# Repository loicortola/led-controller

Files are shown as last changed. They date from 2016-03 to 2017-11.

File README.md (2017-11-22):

# Led Controller

All-in-one OpenSource & Open Hardware Smartphone-controlled Led Controller for ESP-8266.  

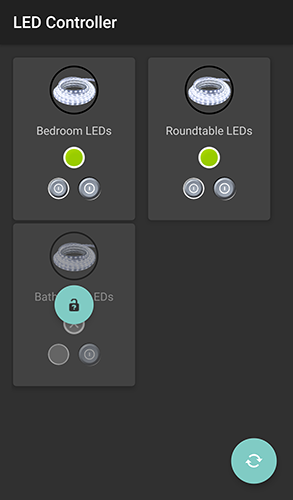
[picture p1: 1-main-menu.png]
main-menu

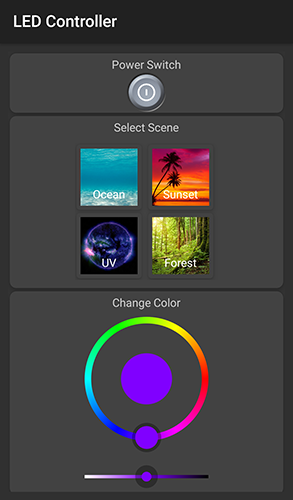
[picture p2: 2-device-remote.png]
device-remote


## Requirements

The current version has been rewritten entirely in C/C++ to use along with Arduino IDE.

 * Install Arduino IDE
 * [Install ESP8266 model](https://github.com/esp8266/Arduino)
 * [Install ESP8266 Arduino filesystem uploader plugin](https://github.com/esp8266/arduino-esp8266fs-plugin)
 * Install EAGLE or KiCAD (only if you want to edit the board hardware design)
**NB: You can find a previous version for NodeMCU (in LUA) in previous commits.**

## Schematics
This board is Open-Hardware.  
All parts and schematics are available in the hardware folder.  
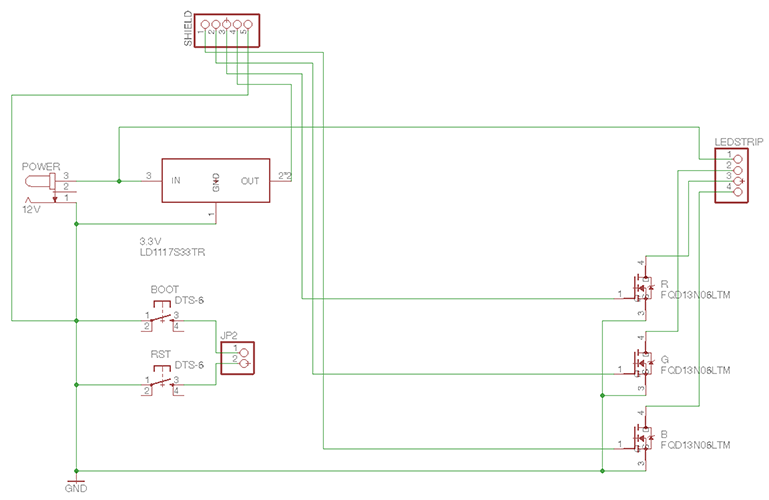
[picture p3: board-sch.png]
main-board-schematics

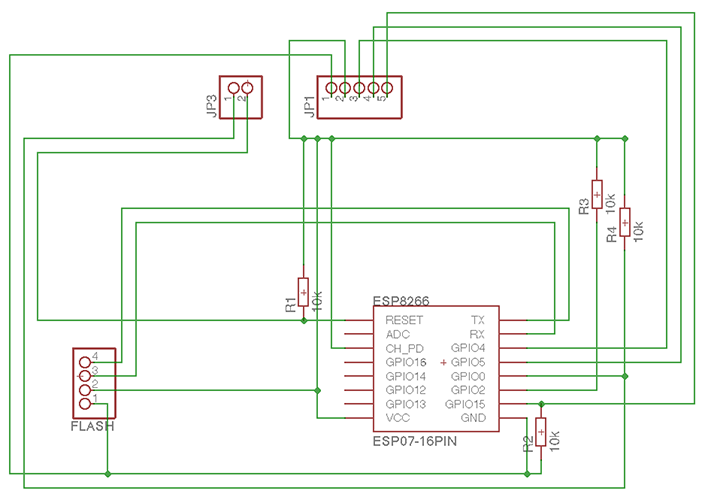
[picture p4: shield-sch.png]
shield-schematics


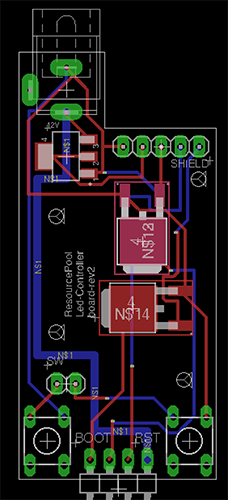
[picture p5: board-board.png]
main-board-board

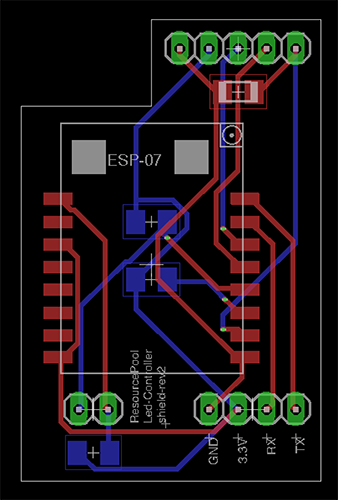
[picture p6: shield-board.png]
shield-board


## Setup

 * Transfer the content using Arduino onto your ESP-8266.
 * Transfer the files in data/ with the filesystem uploader plugin.

Warning: Your ESP needs to be in bootloader mode!

## Setup Instructions

### 1. First setup
At first power-on, your LEDs will be blinking green. Your device is waiting for you to configure it.

Find the Wifi Access-Point named "Led-SOMETHING", and connect to it from your laptop, your smartphone, or any Wireless device.  
Open your browser and access http://10.0.0.1  

Enter your Wifi credentials, and choose a personal password key for your LED controller. This password will be asked everytime you want to bind your controller to an external control system.

When registered, your LED Controller will restart and blink yellow. Yellow means "I am trying to connect with the credentials you gave me".

If the LED Controller succeeds, the light will turn Blue and stop blinking. That means your LED Controller setup is successful.

Otherwise, after 10 seconds, the LEDs will blink red. This means that your settings did not work correctly.
You can safely reboot (take off the plug, and plug it on again) your LED Controller and start over.

### 2. Updates
Any Wifi network/password change will require the LED Controller to be setup once again. This is a safety measure.

### 3. Android App
When you have installed the APK on your phone, simply launch it and click on "Re-Sync" in the settings tab.
Make sure you are connected on the same wifi network as your LED Controller.

When your Controller is successfully found, a Dialog will pop-up so you can enter your password key.

You're done! The Controller is now successfully paired to your Android App!

** Seeking contributions to improve UX and features of the app.**

### Contributors
All contributions are welcome.
If you want to join the project, please let me know on Twitter [@LoicOrtola](https://twitter.com/loicortola) or start sending PRs ;)

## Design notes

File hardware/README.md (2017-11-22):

# Led-Controller Parts

Here are the necessary parts to buy for your Led Controller board:

 * 1x [PJ-002A JACK 2X5.5MM](https://www.digikey.fr/product-detail/en/cui-inc/PJ-002A/CP-002A-ND/96962)
 * 1x [LD1117S33TR - IC REG LINEAR 3.3V 800MA SOT223](https://www.digikey.com/product-detail/en/stmicroelectronics/LD1117S33TR/497-1242-1-ND/586242)
 * 3x [FQD13N06LTM - MOSFET N-CH 60V 11A DPAK](https://www.digikey.com/product-detail/en/on-semiconductor/FQD13N06LTM/FQD13N06LTMCT-ND/3042598)
 * 2x [679-2428-ND - SWITCH TACTILE 12V 0.05A](https://www.digikey.com/product-detail/en/apem-inc/MJTP1230/679-2428-ND/1798037)
 * 4x [RC1206FR-0710KL - 10KOhms 1% RESISTOR 1206](https://www.digikey.fr/product-detail/en/yageo/RC1206FR-0710KL/311-10.0KFRCT-ND/731430)
 * 1x [ESP-8266 - ESP12](https://fr.aliexpress.com/wholesale?catId=0&initiative_id=SB_20171122124705&SearchText=esp12)
 * 1x [15PIN-HEAD](https://fr.aliexpress.com/wholesale?catId=0&initiative_id=SB_20171122124828&SearchText=male+pin+header)

You can also order the PCBs directly from Aisler.net:  
[Board PCB](https://aisler.net/loicortola/led-controller/board-pcb)
[Shield PCB](https://aisler.net/loicortola/led-controller/shield)

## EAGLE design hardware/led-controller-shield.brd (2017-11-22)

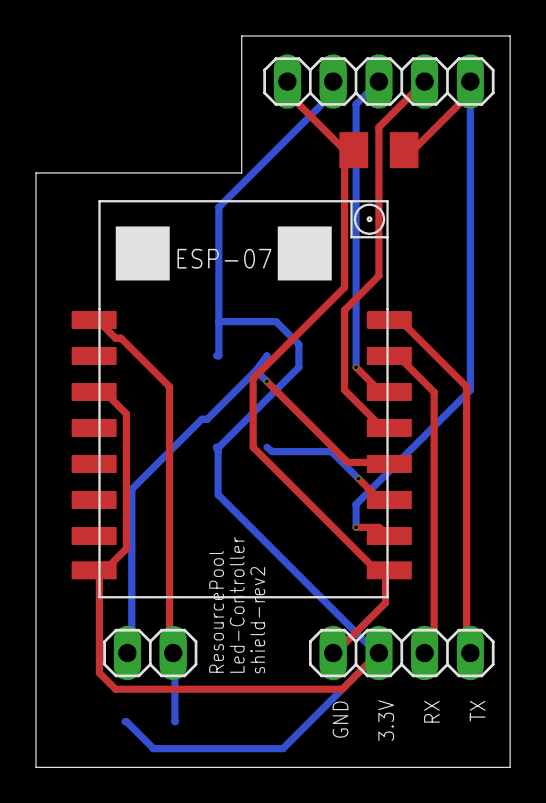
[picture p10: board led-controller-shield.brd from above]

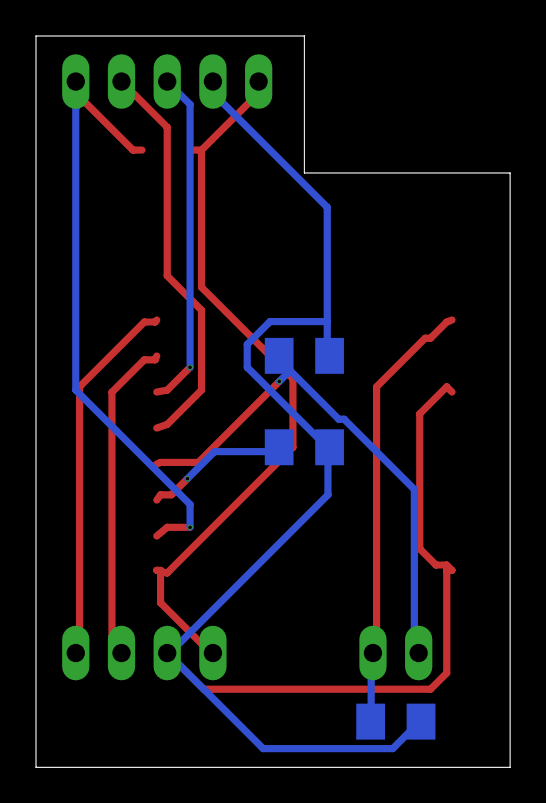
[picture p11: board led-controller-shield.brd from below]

Board: 2 copper layers, 26.3 x 40.6 mm, 8 parts (3 on the bottom side), 10 nets.

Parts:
LED-CONTROLLER-SHIELD1:ESP8266: ESP07-16PIN
LED-CONTROLLER-SHIELD1:FLASH: 1X04
LED-CONTROLLER-SHIELD1:JP1: 1X05
LED-CONTROLLER-SHIELD1:JP3: 1X02
LED-CONTROLLER-SHIELD1:R1, LED-CONTROLLER-SHIELD1:R2, LED-CONTROLLER-SHIELD1:R3, LED-CONTROLLER-SHIELD1:R4: 10k; M1206

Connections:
LED-CONTROLLER-SHIELD1:+3.3V: LED-CONTROLLER-SHIELD1:ESP8266.CH_PD, LED-CONTROLLER-SHIELD1:ESP8266.VCC, LED-CONTROLLER-SHIELD1:FLASH.2, LED-CONTROLLER-SHIELD1:JP1.2, LED-CONTROLLER-SHIELD1:R1.2, LED-CONTROLLER-SHIELD1:R3.2, LED-CONTROLLER-SHIELD1:R4.2
LED-CONTROLLER-SHIELD1:B: LED-CONTROLLER-SHIELD1:ESP8266.GPIO15, LED-CONTROLLER-SHIELD1:JP1.5, LED-CONTROLLER-SHIELD1:R2.2
LED-CONTROLLER-SHIELD1:BOOT: LED-CONTROLLER-SHIELD1:ESP8266.GPIO0, LED-CONTROLLER-SHIELD1:JP3.1, LED-CONTROLLER-SHIELD1:R4.1
LED-CONTROLLER-SHIELD1:G: LED-CONTROLLER-SHIELD1:ESP8266.GPIO5, LED-CONTROLLER-SHIELD1:JP1.4
LED-CONTROLLER-SHIELD1:GND: LED-CONTROLLER-SHIELD1:ESP8266.GND, LED-CONTROLLER-SHIELD1:FLASH.1, LED-CONTROLLER-SHIELD1:JP1.1, LED-CONTROLLER-SHIELD1:R2.1
LED-CONTROLLER-SHIELD1:N$6: LED-CONTROLLER-SHIELD1:ESP8266.GPIO2, LED-CONTROLLER-SHIELD1:R3.1
LED-CONTROLLER-SHIELD1:N$8: LED-CONTROLLER-SHIELD1:ESP8266.TX, LED-CONTROLLER-SHIELD1:FLASH.4
LED-CONTROLLER-SHIELD1:N$9: LED-CONTROLLER-SHIELD1:ESP8266.RX, LED-CONTROLLER-SHIELD1:FLASH.3
LED-CONTROLLER-SHIELD1:R: LED-CONTROLLER-SHIELD1:ESP8266.GPIO4, LED-CONTROLLER-SHIELD1:JP1.3
LED-CONTROLLER-SHIELD1:RST: LED-CONTROLLER-SHIELD1:ESP8266.REST, LED-CONTROLLER-SHIELD1:JP3.2, LED-CONTROLLER-SHIELD1:R1.1

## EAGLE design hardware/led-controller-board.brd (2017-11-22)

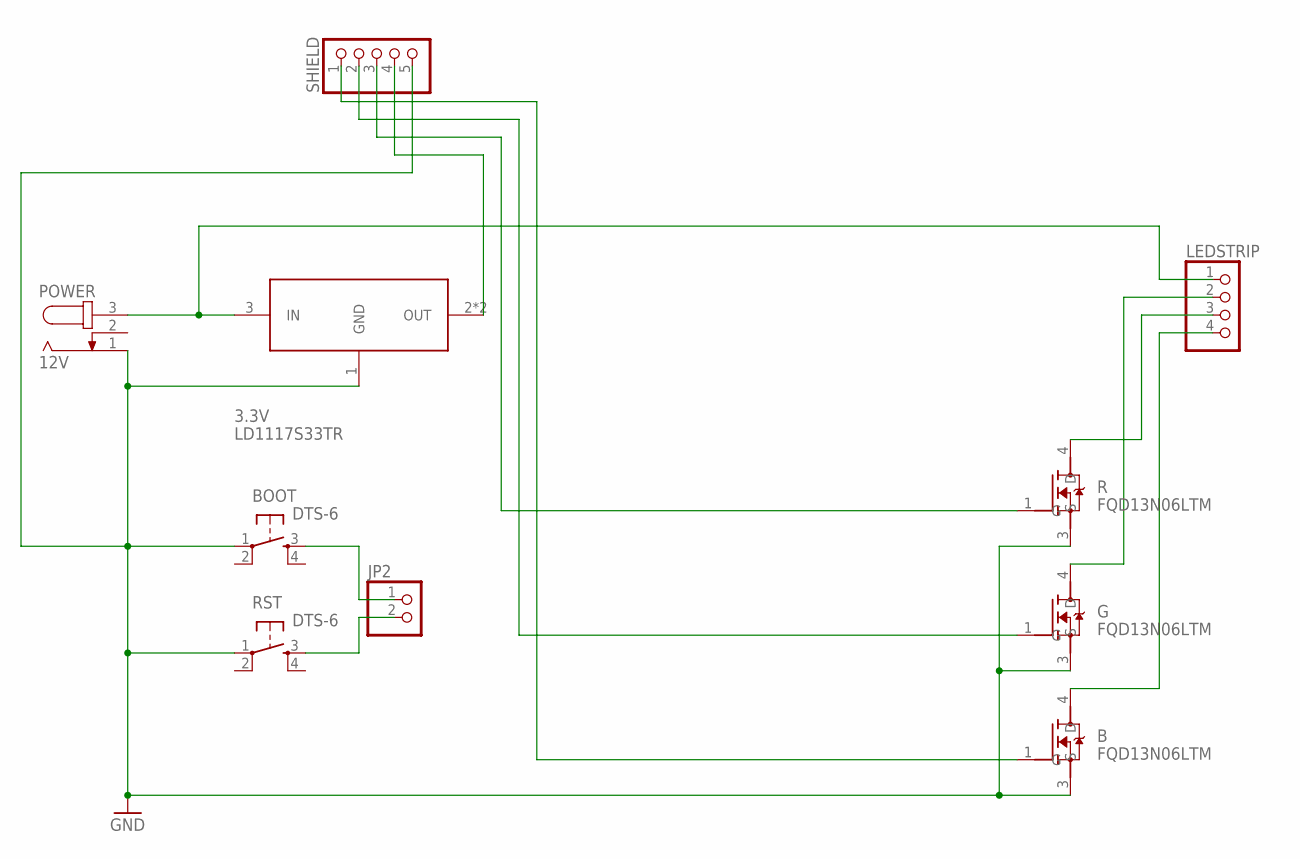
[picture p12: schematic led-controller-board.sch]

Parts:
3.3V: LD1117S33TR; SOT223
B: FQD13N06LTM; TO229P991X239-3N
BOOT: DTS-6
G: FQD13N06LTM; TO229P991X239-3N
JP2: PINHD-1X2; 1X02
LEDSTRIP: PINHD-1X4/90; 1X04/90
POWER: 12V; SPC4078
R: FQD13N06LTM; TO229P991X239-3N
RST: DTS-6
SHIELD: PINHD-1X5; 1X05

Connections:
GND: 3.3V.1 (GND), B.3 (S), BOOT.1, G.3 (S), POWER.1, R.3 (S), RST.1, SHIELD.5
unnamed: 3.3V.3 (IN), LEDSTRIP.1, POWER.3
unnamed: BOOT.3, JP2.1
unnamed: JP2.2, RST.3
unnamed: 3.3V.2 (OUT), 3.3V.4 (OUT), SHIELD.4
unnamed: B.1 (G), SHIELD.1
unnamed: R.1 (G), SHIELD.3
unnamed: G.1 (G), SHIELD.2
unnamed: G.4 (D), LEDSTRIP.2
unnamed: LEDSTRIP.3, R.4 (D)
unnamed: B.4 (D), LEDSTRIP.4

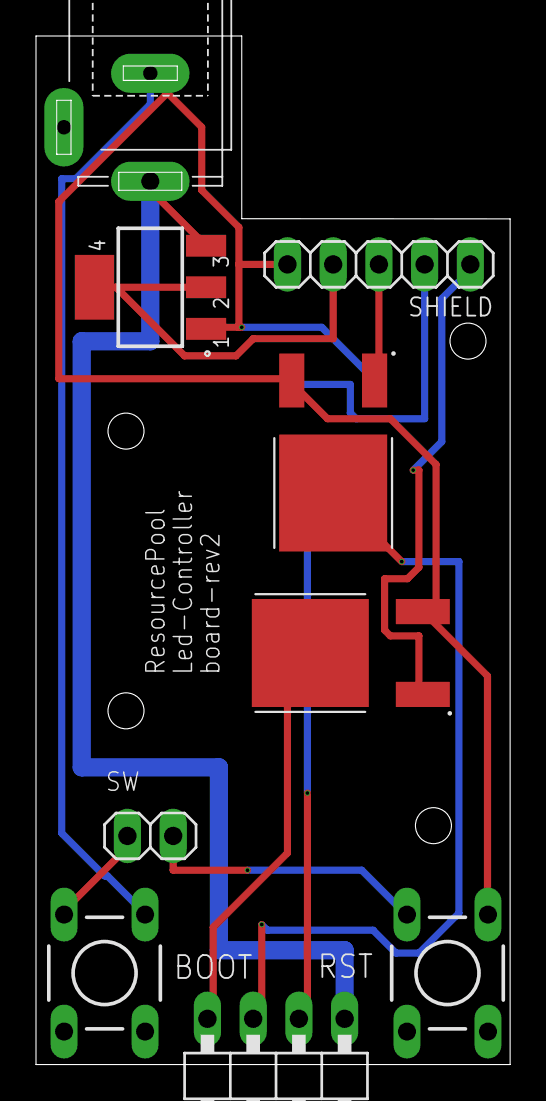
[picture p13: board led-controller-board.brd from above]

Board: 2 copper layers, 26.3 x 57.1 mm, 10 parts (1 on the bottom side), 11 nets.

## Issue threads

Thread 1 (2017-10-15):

led type and pinout?

opus506, 2017-10-15:
What type of LEDs is this designed for?
ws2812b, 12v rgb, etc.

what or where is the pinout setup?

loicortola, 2017-10-15:
Hello @opus506
this is made for 5050 (aka 12v RGB) LEDs.
The pinout is easy, although requires external components (resistors and transistors) to ensure enough current drawn to the LEDs.
I haven't sent the schematics for now, would you be interested in it?

opus506, 2017-10-15:
I would love it! I really like how you've set things to work as
multi-master and multi-node objects. Well done my friend

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

loicortola, 2017-10-15:
Thanks a lot ;)

There is still some work that can be made on the Android App (I really coded it in a few hours to have something working out of the box) but it works well.
Also, I implemented generic command patterns so that we can support literally any kind of IoT equipment in the future.

If you are a developer, know that contributions are welcome ;)

I am not good with Eagle schematics yet, so I just drew the circuit.
For 3.3V, I used a regular 3.3V voltage regulator which draws power directly from the 12V input.
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

 * I use PIN 5 for red, PIN 4 for green, and PIN 15 for blue.
 * Each pin is connected to the base of a NPN transistor
 * The emitter of each transistor is connected to GND
 * The collector of each transistor is connected to a pull-up transistor of 200k ohm (+12V) and to the related input of the led strip.

The only thing I haven't solved yet (poor electronics skills I guess) is high thermal dissipation of the 3.3V power-supply. I think a step-down power converter would be more appropriate than a simple 3.3V voltage regulator. (It doesn't matter though, the device works perfectly, I just think efficiency and power consumption could be slightly lower if using a step-down).

opus506, 2017-10-15:
I built a prototype board for this exact purpose a while back. 2n2222a
transistors give each channel 800mah, which can fork into 3 line rails if
desired. Pretty sure its the same except for the placement of the resistors.

On Sun, Oct 15, 2017 at 3:52 PM, Loïc Ortola <notifications@github.com>
wrote:

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

loicortola, 2017-10-19:
Hahaha awesome!
I'm currently looking at other circuits (because I want to make the transition from Wifi to ZigBee Light Link compatible, in order to use the controller with Philips HUE, LiFx and other Home automation device), and the guys are using MOSFETs instead, as those can reach more current.
I think the source of heat and power-loss is the stepdown though (for Arduino).

loicortola, 2017-10-19:
https://learn.adafruit.com/rgb-led-strips/usage

loicortola, 2017-10-19:
In the end, that's what it would look like:

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

loicortola, 2017-10-19:
R1=R2=R3=R4=10k

loicortola, 2017-11-07:
Finished PCB prototype.
Here is the final look :
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

opus506, 2017-11-07:
The area behind the back of the antenna is supposed to be air gaped
according to espressif. Everything looks great though.

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

loicortola, 2017-12-29:
I consider this issue resolved. Take a look at the updated schematics and board :)

Closed 2017-12-29.

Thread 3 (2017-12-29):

Support for RGBW LEDs

loicortola, 2017-12-29:
To this point, the system supports only RGB LEDs.
RGB+W / RGBW LEDs support is now preferred.

loicortola, 2017-12-29:
[RGBWWCW](https://french.alibaba.com/product-detail/5-color-in-1-chip-rgb-cct-12v-24v-5050smd-rgbww-rgbw-led-strip-waterproof-ip68-for-outdoor-lighting-60725631369.html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)

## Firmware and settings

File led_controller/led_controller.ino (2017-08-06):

#include <ESP8266WebServer.h>
#include <ESP8266mDNS.h>
#include <FS.h>
#include "DAO.h"
#include "LedController.h"
#include "WifiController.h"
#include "Color.h"
#include "Animation.h"
#include "AnimationRequestHandler.h"
#include "StatusRequestHandler.h"
#include "ColorRequestHandler.h"
#include "PowerRequestHandler.h"
#include "WifiRequestHandler.h"
#include "SSDPDevice.h"

ESP8266WebServer server(80); // on instancie un serveur ecoutant sur le port 80
DAO dao;
LedController lc(&dao);
WifiController wc(&dao, &lc);
AnimationRequestHandler animationHandler(server, lc);
StatusRequestHandler statusHandler(server, lc);
ColorRequestHandler colorHandler(server, lc);
PowerRequestHandler powerHandler(server, lc);
WifiRequestHandler wifiHandler(server, lc, wc);

void setup(void){

  Serial.begin(115200);
  Serial.println("");

  // First thing to do is load the leds
  lc.begin();
  // Then load wifi controller
  wc.begin();
  if (wc.isConfigured()) {
    start();
  } else {
    configure();
  }
  // Get heap status, analog input value and all GPIO statuses in one json call
  server.on("/health", HTTP_GET, [](){
    String json = "{";
    json += "\"heap\":"+String(ESP.getFreeHeap());
    json += "}";
    server.send(200, "application/json charset=utf-8;", json);
  });
  server.begin();
}

bool isAuthenticated(const String& password) {
  if (!server.hasHeader("Authorization")) {
    return false;
  }
  String apiKey = server.header("Authorization");
  String validKey = "ApiKey " + password;
  if (apiKey != validKey) {
    return false;
  }
  return true;
}

auto authenticate(void (*handler)(), String apiKey) {
  return [handler, apiKey]() {
    if (!isAuthenticated(apiKey)) {
      server.send(401, "application/json charset=utf-8;", "{\"message\":\"You need to provide a valid Authorization Header with your ApiKey\"}");
      return;
    }
    handler();
  };
}

void start() {
  lc.loadDefaults();
  wc.connect();
  String apiKey = dao.getPassword();

  // Status route
  server.on("/api/status", HTTP_GET, authenticate([statusHandler](){statusHandler.getHandler();}, apiKey));

  // Switch route
  server.on("/api/power", HTTP_POST, authenticate([powerHandler](){powerHandler.postHandler();}, apiKey));

  // Animate route
  server.on("/api/animate", HTTP_POST, authenticate([animationHandler](){animationHandler.postHandler();}, apiKey));

  // Color route
  server.on("/api/color", HTTP_POST, authenticate([colorHandler](){colorHandler.postHandler();}, apiKey));

  // SSDP route
  server.on("/description.xml", HTTP_GET, []() {
    SSDPDevice.schema(server.client());
  });
  // Serve static files
  SPIFFS.begin();
  server.serveStatic("/static/", SPIFFS, "/");
  String name = "Led Controller " + String(ESP.getChipId());
  SSDPDevice.setName(name);
  SSDPDevice.setDeviceType("urn:schemas-upnp-org:device:DimmableRGBLight:2");
  SSDPDevice.setSchemaURL("description.xml");
  SSDPDevice.setSerialNumber(ESP.getChipId());
  SSDPDevice.setURL("/description.xml");
  SSDPDevice.setModelName(name);
  SSDPDevice.setModelNumber(String(ESP.getChipId()));
  SSDPDevice.setManufacturer("Resourcepool.io");
}

void configure() {
  // Blink green <=> configuration mode
  lc.blink(new Color(0, 255, 0));

  // Get SSIDs route
  server.on("/api/ssids", [wifiHandler](){wifiHandler.getHandler();});
  server.on("/api/register", [wifiHandler](){wifiHandler.postHandler();});
  server.on("/api/restart", [](){
    server.send(200, "application/json charset=utf-8;", "{\"message\":\"Success\"}");
    ESP.restart();
  });
  server.on("/api/clear", [](){
    dao.clear();
    server.send(200, "application/json charset=utf-8;", "{\"message\":\"Success\"}");
    ESP.restart();
  });
  // Serve static files
  SPIFFS.begin();
  server.serveStatic("/", SPIFFS, "/index.html");
  server.serveStatic("/static/", SPIFFS, "/");
}

int c = 0;
void loop(void){
  server.handleClient();
  SSDPDevice.handleClient();
  if (c++ == 40000) {
    c = 0;
    Serial.println(ESP.getFreeHeap());
  }
  yield();
}

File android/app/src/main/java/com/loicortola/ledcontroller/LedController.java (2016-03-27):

package com.loicortola.ledcontroller;

import android.content.Context;
import android.graphics.Color;
import android.os.AsyncTask;
import android.preference.PreferenceManager;
import android.util.Log;

import java.io.IOException;

import okhttp3.MediaType;
import okhttp3.OkHttpClient;
import okhttp3.Request;
import okhttp3.RequestBody;
import okhttp3.Response;

/**
 * Created by Loïc Ortola on 23/01/2016.
 */
public class LedController {

    public static final String PREF_KEY = "pref_key";
    public static final String PREF_HOST = "pref_host";

    public static final MediaType JSON = MediaType.parse("application/json; charset=utf-8");
    private OkHttpClient client = new OkHttpClient();
    private Context ctx;
    private CheckOnlineTask checkOnlineTask;
    private ChangeColorTask changeColorTask;
    private AnimateTask animateTask;
    private SwitchTask switchTask;
    private LedControllerListener l;

    public interface LedControllerListener {

        void onSwitched(Boolean success);

        void onColorChange(Boolean success);

        void onAnimate(Boolean success);

        void onCheckOnline(Boolean success);
    }

    public LedController(Context ctx, LedControllerListener l) {
        this.ctx = ctx.getApplicationContext();
        this.l = l;
        checkOnlineTask = new CheckOnlineTask();
        checkOnlineTask.execute();
    }

    public void setHost(String host) {
        PreferenceManager.getDefaultSharedPreferences(ctx).edit().putString(PREF_HOST, host).commit();
    }

    public void setKey(String key) {
        PreferenceManager.getDefaultSharedPreferences(ctx).edit().putString(PREF_KEY, key).commit();
    }

    public void changeColor(int color) {
        if (changeColorTask != null && changeColorTask.getStatus().equals(AsyncTask.Status.RUNNING)) {
            changeColorTask.cancel(true);
        }
        changeColorTask = new ChangeColorTask(color);
        changeColorTask.execute();
    }

    public void animate(int color, int time) {
        if (animateTask != null && animateTask.getStatus().equals(AsyncTask.Status.RUNNING)) {
            animateTask.cancel(true);
        }
        animateTask = new AnimateTask(color, time);
        animateTask.execute();
    }

    public void switchOnOff() {
        if (switchTask != null && switchTask.getStatus().equals(AsyncTask.Status.RUNNING)) {
            switchTask.cancel(true);
        }
        switchTask = new SwitchTask();
        switchTask.execute();
    }

    public void cancelTasks() {
        if (checkOnlineTask != null) {
            checkOnlineTask.cancel(true);
        }
        if (changeColorTask != null) {
            changeColorTask.cancel(true);
        }
        if (animateTask != null) {
            animateTask.cancel(true);
        }
        if (switchTask != null) {
            switchTask.cancel(true);
        }
    }

    private class CheckOnlineTask extends AsyncTask<Void, Void, Boolean> {


        public CheckOnlineTask() {
        }

        @Override
        protected Boolean doInBackground(Void... params) {
            String url = new StringBuilder(PreferenceManager.getDefaultSharedPreferences(ctx).getString(PREF_HOST, "http://localhost"))
                    .append("/health")
                    .toString();
            Log.w("LedController", url);
            // Body is empty
            Request request = new Request.Builder()
                    .url(url)
                    .build();

            try {
                Response response = client.newCall(request).execute();
                Log.w("LedController", "Response code: " + response.code());
                return response.code() == 200;
            } catch (IOException e) {
                Log.w("LedController", "Exception occured: " + e.getMessage());
                return false;
            }
        }

        @Override
        protected void onPostExecute(Boolean success) {
            l.onCheckOnline(success);
        }
    }

    private class SwitchTask extends AsyncTask<Void, Void, Boolean> {

        public SwitchTask() {
        }

        @Override
        protected Boolean doInBackground(Void... params) {
            String url = new StringBuilder(PreferenceManager.getDefaultSharedPreferences(ctx).getString(PREF_HOST, "http://localhost"))
                    .append("/switch")
                    .toString();
            // Body is empty
            RequestBody body = RequestBody.create(JSON, "{}");
            Request request = new Request.Builder()
                    .header("x-api-key", PreferenceManager.getDefaultSharedPreferences(ctx).getString(PREF_KEY, ""))
                    .url(url)
                    .post(body)
                    .build();
            try {
                Response response = client.newCall(request).execute();
                return response.code() == 200;
            } catch (IOException e) {
                return false;
            }
        }

        @Override
        protected void onPostExecute(Boolean success) {
            l.onSwitched(success);
        }
    }

    private class ChangeColorTask extends AsyncTask<Void, Void, Boolean> {

        int red;
        int green;
        int blue;

        public ChangeColorTask(int color) {
            red = Color.red(color);
            green = Color.green(color);
            blue = Color.blue(color);
        }

        @Override
        protected Boolean doInBackground(Void... params) {
            String url = new StringBuilder(PreferenceManager.getDefaultSharedPreferences(ctx).getString(PREF_HOST, "http://localhost"))
                    .append("/color?red=")
                    .append(red)
                    .append("&green=")
                    .append(green)
                    .append("&blue=")
                    .append(blue)
                    .toString();
            // Body is empty
            RequestBody body = RequestBody.create(JSON, "{}");
            Request request = new Request.Builder()
                    .header("x-api-key", PreferenceManager.getDefaultSharedPreferences(ctx).getString(PREF_KEY, ""))
                    .url(url)
                    .post(body)
                    .build();

            try {
                Response response = client.newCall(request).execute();
                return response.code() == 200;
            } catch (IOException e) {
                return false;
            }
        }

        @Override
        protected void onPostExecute(Boolean success) {
            l.onColorChange(success);
        }
    }

    private class AnimateTask extends AsyncTask<Void, Void, Boolean> {

        int red;
        int green;
        int blue;
        int time;

        public AnimateTask(int color, int time) {
            red = Color.red(color);
            green = Color.green(color);
            blue = Color.blue(color);
            this.time = time;
        }
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

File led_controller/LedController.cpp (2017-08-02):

#include <Arduino.h>
#include "LedController.h"
#include "Animation.h"
#include "AnimationSet.h"
#include "Color.h"
#include "DAO.h"
extern "C" {
#include "user_interface.h"
}

#define BLINK_THRESHOLD 500

/**
 * The Led Controller performs all led operations
 */
LedController::LedController(DAO* dao) {
  this->dao = dao;
  this->currentAnimationStep = -1;
}

void onTick(void* instance) {
  ((LedController *) instance)->onAnimationTick();
}

void LedController::begin() {
  // Initialize timer
  os_timer_setfn(&(this->timer), onTick , this);

  // Initialize color
  Color* black = new Color(0, 0, 0);
  this->changeColor(black);
  delete black;
}

void LedController::update() {
}

void LedController::stop() {
  this->blinking = false;
  switchOff();
  os_timer_disarm(&(this->timer));
}

void LedController::loadDefaults() {
    if (!this->isSwitchedOn()) {
      switchOff();
      return;
    }
    switchOn();
}

void LedController::toggle() {
  if (isSwitchedOn()) {
    switchOff();
  } else {
    switchOn();
  }
}

void LedController::switchOn() {
  dao->storeState(STATE_SWITCH, true);
  int mode = this->getMode();
  if (mode == 0) {
    if (currentBlink != NULL) {
      // Blink mode
      this->changeColor(this->currentBlink);
    }
  } else if (mode == 1) {
    // Plain Color mode
    Color *c = this->getColor();
    this->changeColor(c);
    delete c;
  } else if (mode == 2) {
    // Animate mode
    this->startAnimation(this->getAnimation());
  } else if (mode == 3) {
    // AnimateSet mode
    this->startAnimationSet(this->getAnimationSet());
  }
}

void LedController::switchOff() {
  if (this->getMode() != 0) {
    // SwitchOff is used internally with blink mode
    stopAnimation();
    clearAnimations();
  }
  Color* black = new Color(0,0,0);
  this->changeColor(black);
  delete black;
  dao->storeState(STATE_SWITCH, false);
}

bool LedController::isSwitchedOn() {
  return dao->getState(STATE_SWITCH);
}

void LedController::blink(Color* c) {
  // Set blinking mode
  setMode(0);
  blinking = true;
  currentBlink = c;
  changeColor(c);
  startBlinking(c);
}

int LedController::getMode() {
  return dao->getMode();
}

void LedController::setMode(int mode) {
  dao->storeMode(mode);
}

Color* LedController::getColor() {
  return dao->getColor();
}

void LedController::setColor(Color* c) {
  this->stopAnimation();
  dao->storeColor(c);
  this->setMode(1);
  this->switchOn();
}

void LedController::changeColor(Color* c) {
  analogWrite(LED_R_PIN, min(1023, 4 * c->getR()));
  analogWrite(LED_G_PIN, min(1023,  4 * c->getG()));
  analogWrite(LED_B_PIN, min(1023,  4 * c->getB()));
}

void LedController::stopAnimation() {
  os_timer_disarm(&(this->timer));
  blinking = false;
}

void LedController::startAnimation(Animation* a) {
  // Max Ops = 255*6 = 1.5k. But increment of 2, so half.
  // Min looptime = 4s
  int ops = a->getR() + a->getG() + a->getB();
  int triggerMs = a->getLoopTime() / ops;
  os_timer_arm(&(this->timer), triggerMs, true);
}

void LedController::startAnimationSet(AnimationSet* as) {
  if (this->currentAnimationStep == as->getSize()) {
    this->currentAnimationStep = 0;
  }
  if (currentAnimationStep == -1) {
    Animation* firstAnim = as->getItems()[0];
    currentAnimation = new Animation(0,0,0, firstAnim->getLoopTime(), new Color(firstAnim->getR(), firstAnim->getG(), firstAnim->getB()));
  } else {
    currentAnimation = as->getItems()[currentAnimationStep]->clone();
    currentAnimation->reset();
  }
  currentAnimation->printTo(Serial);
  int ops = max(1, max(max(abs(currentAnimation->getR() - currentAnimation->getTargetColor()->getR()),
                    abs(currentAnimation->getG() - currentAnimation->getTargetColor()->getG())),
                    abs(currentAnimation->getB() - currentAnimation->getTargetColor()->getB())));
  int triggerMs = currentAnimation->getLoopTime() / ops;
  os_timer_arm(&(this->timer), triggerMs, true);
}

void LedController::startBlinking(Color* c) {
  // Blink every second
  os_timer_arm(&(this->timer), 1000, true);
}

Animation* LedController::getAnimation() {
  if (this->currentAnimation == NULL) {
    Color* c = dao->getColor();
    int loopTime = dao->getLoopTime();
    this->currentAnimation = new Animation(c->getR(), c->getG(), c->getB(), loopTime);
    delete c;
  }
  return currentAnimation;
}

AnimationSet* LedController::getAnimationSet() {
  if (this->currentAnimationSet == NULL) {
    AnimationSet* as = dao->getAnimationSet();
    this->currentAnimationSet = as;
  }
  return currentAnimationSet;
}

void LedController::onAnimationTick() {
  if (blinking) {
    this->toggle();
  } else {
    if (this->currentAnimation->isFinished()) {
      this->stopAnimation();
      delete this->currentAnimation;
      this->currentAnimation = NULL;
      this->currentAnimationStep++;
      this->startAnimationSet(this->currentAnimationSet);
    } else {
      Color* c = this->currentAnimation->getNextColor();
      this->changeColor(c);
    }
  }
}

void LedController::clearAnimations() {
  delete this->currentAnimationSet;
  delete this->currentAnimation;
  this->currentAnimationStep = -1;
  this->currentAnimation = NULL;
  this->currentAnimationSet = NULL;
}

void LedController::animate(Animation* a) {
  this->stopAnimation();
  this->clearAnimations();
  this->currentAnimation = a;
  Color* initialColor = new Color(a->getR(), a->getG(), a->getB());
  dao->storeColor(initialColor);
  delete initialColor;
  dao->storeLoopTime(a->getLoopTime());
  this->setMode(2);
  this->switchOn();
}


void LedController::animateSet(AnimationSet* as) {
  this->stopAnimation();
  this->clearAnimations();
  this->currentAnimationSet = as;
  dao->storeAnimationSet(as);
  this->setMode(3);
  yield();
  this->switchOn();
}

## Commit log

2016-03-27 Added ON/OFF Switch
2016-03-27 Added Switch and multicast DNS Lookup features in Android app
2016-03-28 Refactored Android app... Aoutch
    [app_bar_drawer.xml]
2017-07-30 WIP Switched from NodeMCU to ESP + Arduino
    Complete rewrite in C/C++
2017-07-31 Added ApiKey support, fixed Password issue, WIP for AnimationSet
    [led_controller.ino]
2017-08-02 Fixed really cool bugs. Divide by zero, animation flaws
    [LedController.cpp]
2017-11-22 Added schematics rev2, changed README
    [led-controller-board.brd, led-controller-board.sch, led-controller-shield.brd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]
